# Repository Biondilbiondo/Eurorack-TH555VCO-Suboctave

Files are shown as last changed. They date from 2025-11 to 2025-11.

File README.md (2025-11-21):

# TH555 SUB VCO

This is a remake of eurorack module for the excellent and fully-analog Thomas Henry 555 VCO [[1](https://electro-music.com/forum/topic-54623.html)] [[2](https://github.com/gerb-ster/TH-555-VCO)] [[3](https://www.eddybergman.com/2020/12/synthesizer-build-part-37-thomas-henry.html)].
I added some features and tweaks to the module (inventing very little...) to make it more appealing to be built in 2025.

1. Added a sub-octave stage chained with the module to generate a square, sawtooth and triangle waves 1 octave below, and a square wave 2 octaves below; this is basically taken from [[4](https://electro-music.com/wiki/pmwiki.php?n=Schematics.WaveThingMultiply-DivideWaveShapingCircuit)] 
2. Added an octave switch using a rotatory switch widely available in the DIY eurorack stores (the same of MTM turing machine [[5](https://www.musicthing.co.uk/Turing-Machine/)]
3. Drastically reduced the range of coarse/fine knobs to be used in combination with the octave switch (COARSE = +/- 2 octaves; FINE = +/- 3 semitones)
4. Added a LFO function, with larger range for the COARSE/FINE knobs, and a configurable basic frequence.
5. Switched input/output to thonkiconn
6. Removed the manually matched pair of transistors in favor of the in-chip matched BCM857BS
7. All components are now SMT (easy hand soldered SOIC, 0603 passives)

## Versions
# 0.1
First take, this version had several errors, both schematic copying errors and in the sub-octabve section. This version was used to develop v 0.2 but sources are lost.

# 0.2
Almost completely working version. 

Improvements wrt vs 0.1
- ✅ The clock feed circuit for the sub-octave is completely redesigned
- ✅ Several minor copying errors have been corrected
- ✅ The panel for octave switch has been corrected
- ✅ Resistors for the octave switch are now marked in the correct order
- ✅ All the trimmer are now in the same format (3214X) + name added for each
Problems:
- ❌ Transistors footprint is incorrect (they shuld be mounted upside-down)
- ❌ The frontpanel interface is not optimal
- ❌ Octave switch is not properly tuned depending on the fluctuation of resistors
- ❌ Calibration is not easy

Also this version was lost.
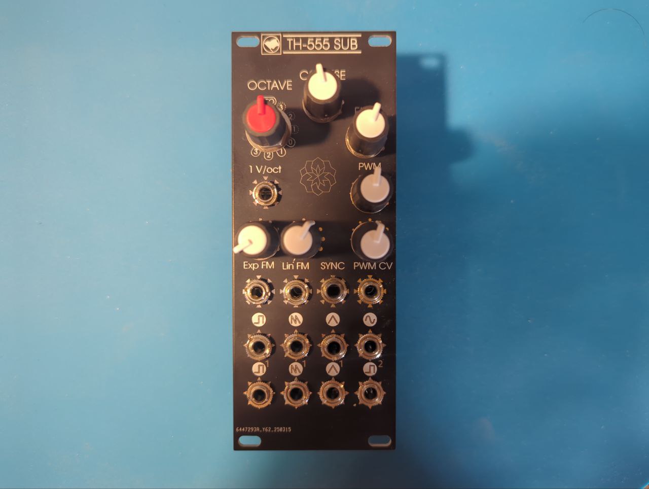
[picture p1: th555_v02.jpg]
Assembled module


# 0.3
This version is the current one, waiting to be built, it was designed starting from reverse-eng of v0.2 from production files. 

Improvements wrt vs 0.2
- ✅ Front panel redesign 
- ✅ Added leds to visualize the wave
- ✅ Corrected footprint of transistors
- ✅ Added a trimmer for octave-switch calibration

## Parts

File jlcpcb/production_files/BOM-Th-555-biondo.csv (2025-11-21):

Comment | Designator | Footprint | LCSC | Quantity
100n | C20 | C_0603_1608Metric_Pad1.08x0.95mm_HandSolder |  | 1
100n | C8 | C_0603_1608Metric_Pad1.08x0.95mm_HandSolder |  | 1
100k | R71 | R_0603_1608Metric_Pad0.98x0.95mm_HandSolder |  | 1
100k | R93 | R_0603_1608Metric_Pad0.98x0.95mm_HandSolder |  | 1
Conn_01x04 | J18 | PinHeader_1x04_P2.54mm_Vertical |  | 1
100k | R76 | R_0603_1608Metric_Pad0.98x0.95mm_HandSolder |  | 1
7.15k | R6 | R_0603_1608Metric_Pad0.98x0.95mm_HandSolder |  | 1
100k | RV11 | Potentiometer_Bourns_3214X_Vertical |  | 1
10k | R75 | R_0603_1608Metric_Pad0.98x0.95mm_HandSolder |  | 1
100k | R25 | R_0603_1608Metric_Pad0.98x0.95mm_HandSolder |  | 1
100R | RV13 | Potentiometer_Bourns_3214X_Vertical |  | 1
11.8k | R38 | R_0603_1608Metric_Pad0.98x0.95mm_HandSolder |  | 1
7.15k | R5 | R_0603_1608Metric_Pad0.98x0.95mm_HandSolder |  | 1
10k | R90 | R_0603_1608Metric_Pad0.98x0.95mm_HandSolder |  | 1
100k | R69 | R_0603_1608Metric_Pad0.98x0.95mm_HandSolder |  | 1
1.5M | R56 | R_0603_1608Metric_Pad0.98x0.95mm_HandSolder |  | 1
10u | C22 | CP_Elec_4x5.8 |  | 1
1n | C24 | C_0603_1608Metric |  | 1
100k | R79 | R_0603_1608Metric_Pad0.98x0.95mm_HandSolder |  | 1
1k | R96 | R_0603_1608Metric_Pad0.98x0.95mm_HandSolder |  | 1
2.2k | R80 | R_0603_1608Metric_Pad0.98x0.95mm_HandSolder |  | 1
150k | R51 | R_0603_1608Metric_Pad0.98x0.95mm_HandSolder |  | 1
10k | R55 | R_0603_1608Metric_Pad0.98x0.95mm_HandSolder |  | 1
100k | R70 | R_0603_1608Metric_Pad0.98x0.95mm_HandSolder |  | 1
100n | C15 | C_0603_1608Metric_Pad1.08x0.95mm_HandSolder |  | 1
1.5k | R12 | R_0603_1608Metric_Pad0.98x0.95mm_HandSolder |  | 1
100k | R98 | R_0603_1608Metric_Pad0.98x0.95mm_HandSolder |  | 1
1M | R48 | R_0603_1608Metric_Pad0.98x0.95mm_HandSolder |  | 1
100k | R88 | R_0603_1608Metric_Pad0.98x0.95mm_HandSolder |  | 1
TL072 | U3 | SOIC-8_3.9x4.9mm_P1.27mm |  | 1
4.7k | R22 | R_0603_1608Metric_Pad0.98x0.95mm_HandSolder |  | 1
2k +3500ppm/K | R53 | R_0603_1608Metric_Pad0.98x0.95mm_HandSolder |  | 1
200k | R30 | R_0603_1608Metric_Pad0.98x0.95mm_HandSolder |  | 1
220n | C14 | C_0603_1608Metric_Pad1.08x0.95mm_HandSolder |  | 1
100n | C17 | C_0603_1608Metric_Pad1.08x0.95mm_HandSolder |  | 1
390R | R10 | R_0603_1608Metric_Pad0.98x0.95mm_HandSolder |  | 1
5.6k | R13 | R_0603_1608Metric_Pad0.98x0.95mm_HandSolder |  | 1
Conn_02x05_Odd_Even | J20 | IDC-Header_2x05_P2.54mm_Vertical |  | 1
1M | R19 | R_0603_1608Metric_Pad0.98x0.95mm_HandSolder |  | 1
100n | C9 | C_0603_1608Metric_Pad1.08x0.95mm_HandSolder |  | 1
1k | R61 | R_0603_1608Metric_Pad0.98x0.95mm_HandSolder |  | 1
100k | R83 | R_0603_1608Metric_Pad0.98x0.95mm_HandSolder |  | 1
237k | R29 | R_0603_1608Metric_Pad0.98x0.95mm_HandSolder |  | 1
20k | R54 | R_0603_1608Metric_Pad0.98x0.95mm_HandSolder |  | 1
100k | R59 | R_0603_1608Metric_Pad0.98x0.95mm_HandSolder |  | 1
10k | R89 | R_0603_1608Metric_Pad0.98x0.95mm_HandSolder |  | 1
10k | R49 | R_0603_1608Metric_Pad0.98x0.95mm_HandSolder |  | 1
TL074 | U7 | SOIC-14_3.9x8.7mm_P1.27mm |  | 1
TL072 | U9 | SOIC-8_3.9x4.9mm_P1.27mm |  | 1
25k | R2 | R_0603_1608Metric_Pad0.98x0.95mm_HandSolder |  | 1
47k | R94 | R_0603_1608Metric_Pad0.98x0.95mm_HandSolder |  | 1
2.2k | R52 | R_0603_1608Metric_Pad0.98x0.95mm_HandSolder |  | 1
10k | R91 | R_0603_1608Metric_Pad0.98x0.95mm_HandSolder |  | 1
100k | R73 | R_0603_1608Metric_Pad0.98x0.95mm_HandSolder |  | 1
1k | R95 | R_0603_1608Metric_Pad0.98x0.95mm_HandSolder |  | 1
10.0k | R4 | R_0603_1608Metric_Pad0.98x0.95mm_HandSolder |  | 1
1k | R65 | R_0603_1608Metric_Pad0.98x0.95mm_HandSolder |  | 1
100n | C7 | C_0603_1608Metric_Pad1.08x0.95mm_HandSolder |  | 1
1n | C5 | C_0603_1608Metric_Pad1.08x0.95mm_HandSolder |  | 1
100k | R97 | R_0603_1608Metric_Pad0.98x0.95mm_HandSolder |  | 1
100k | R34 | R_0603_1608Metric_Pad0.98x0.95mm_HandSolder |  | 1
100p | C13 | C_0603_1608Metric_Pad1.08x0.95mm_HandSolder |  | 1
100n | C10 | C_0603_1608Metric_Pad1.08x0.95mm_HandSolder |  | 1
100n | C18 | C_0603_1608Metric_Pad1.08x0.95mm_HandSolder |  | 1
100k | R15 | R_0603_1608Metric_Pad0.98x0.95mm_HandSolder |  | 1
1M | R50 | R_0603_1608Metric_Pad0.98x0.95mm_HandSolder |  | 1
100k | R74 | R_0603_1608Metric_Pad0.98x0.95mm_HandSolder |  | 1
100k | R24 | R_0603_1608Metric_Pad0.98x0.95mm_HandSolder |  | 1
TL074 | U5 | SOIC-14_3.9x8.7mm_P1.27mm |  | 1
MMBT3904 | Q1 | SOT-23 |  | 1
4.7k | R26 | R_0603_1608Metric_Pad0.98x0.95mm_HandSolder |  | 1
10k | R35 | R_0603_1608Metric_Pad0.98x0.95mm_HandSolder |  | 1
100n | C1 | C_0603_1608Metric_Pad1.08x0.95mm_HandSolder |  | 1
1k | R63 | R_0603_1608Metric_Pad0.98x0.95mm_HandSolder |  | 1
237k | R28 | R_0603_1608Metric_Pad0.98x0.95mm_HandSolder |  | 1
100k | R27 | R_0603_1608Metric_Pad0.98x0.95mm_HandSolder |  | 1
100k | R17 | R_0603_1608Metric_Pad0.98x0.95mm_HandSolder |  | 1
22k | R58 | R_0603_1608Metric_Pad0.98x0.95mm_HandSolder |  | 1
10k | R77 | R_0603_1608Metric_Pad0.98x0.95mm_HandSolder |  | 1
MMBT3906 | Q7 | SOT-23 |  | 1
10k | R43 | R_0603_1608Metric_Pad0.98x0.95mm_HandSolder |  | 1
100k | R60 | R_0603_1608Metric_Pad0.98x0.95mm_HandSolder |  | 1
100k | RV8 | Potentiometer_Bourns_3214X_Vertical |  | 1
14.0k | R36 | R_0603_1608Metric_Pad0.98x0.95mm_HandSolder |  | 1
470p | C6 | C_0603_1608Metric_Pad1.08x0.95mm_HandSolder |  | 1
10n | C25 | C_0603_1608Metric |  | 1
2200pF C0G/NP0 | C2 | C_0603_1608Metric_Pad1.08x0.95mm_HandSolder |  | 1
10k | R9 | R_0603_1608Metric_Pad0.98x0.95mm_HandSolder |  | 1
1.5k | R8 | R_0603_1608Metric_Pad0.98x0.95mm_HandSolder |  | 1
100k | R18 | R_0603_1608Metric_Pad0.98x0.95mm_HandSolder |  | 1
10k | R82 | R_0603_1608Metric_Pad0.98x0.95mm_HandSolder |  | 1
MMBT3904 | Q6 | SOT-23 |  | 1
100n | C11 | C_0603_1608Metric_Pad1.08x0.95mm_HandSolder |  | 1
10u | C19 | CP_Elec_4x5.8 |  | 1
100k | R20 | R_0603_1608Metric_Pad0.98x0.95mm_HandSolder |  | 1
LM13700 | U1 | SOIC-16_3.9x9.9mm_P1.27mm |  | 1
100n | C21 | C_0603_1608Metric_Pad1.08x0.95mm_HandSolder |  | 1
1N4148W | D2 | D_SOD-123 |  | 1
1M | R16 | R_0603_1608Metric_Pad0.98x0.95mm_HandSolder |  | 1
6.04k | R7 | R_0603_1608Metric_Pad0.98x0.95mm_HandSolder |  | 1
10k | R31 | R_0603_1608Metric_Pad0.98x0.95mm_HandSolder |  | 1
25k | RV9 | Potentiometer_Bourns_3214X_Vertical |  | 1
2.2M | R86 | R_0603_1608Metric_Pad0.98x0.95mm_HandSolder |  | 1
100n | C4 | C_0603_1608Metric_Pad1.08x0.95mm_HandSolder |  | 1
100n | C3 | C_0603_1608Metric_Pad1.08x0.95mm_HandSolder |  | 1
22k | R14 | R_0603_1608Metric_Pad0.98x0.95mm_HandSolder |  | 1
4013 | U8 | SOIC-14_3.9x8.7mm_P1.27mm |  | 1
MMBT3904 | Q5 | SOT-23-3_npn |  | 1
100k | R21 | R_0603_1608Metric_Pad0.98x0.95mm_HandSolder |  | 1
8.45k | R3 | R_0603_1608Metric_Pad0.98x0.95mm_HandSolder |  | 1
330k | R47 | R_0603_1608Metric_Pad0.98x0.95mm_HandSolder |  | 1
ICM7555xB | U2 | SOIC-8_3.9x4.9mm_P1.27mm |  | 1
1k | R62 | R_0603_1608Metric_Pad0.98x0.95mm_HandSolder |  | 1
10k | R87 | R_0603_1608Metric_Pad0.98x0.95mm_HandSolder |  | 1
100k | RV14 | Potentiometer_Bourns_3214X_Vertical |  | 1
300k | R11 | R_0603_1608Metric_Pad0.98x0.95mm_HandSolder |  | 1
2.2k | R85 | R_0603_1608Metric_Pad0.98x0.95mm_HandSolder |  | 1
1k | R68 | R_0603_1608Metric_Pad0.98x0.95mm_HandSolder |  | 1
51k | R84 | R_0603_1608Metric_Pad0.98x0.95mm_HandSolder |  | 1
1k | R64 | R_0603_1608Metric_Pad0.98x0.95mm_HandSolder |  | 1
10k | R46 | R_0603_1608Metric_Pad0.98x0.95mm_HandSolder |  | 1
BCM857BS | U6 | SOT-363_SC-70-6 |  | 1
2.2M | R45 | R_0603_1608Metric_Pad0.98x0.95mm_HandSolder |  | 1
200k | R32 | R_0603_1608Metric_Pad0.98x0.95mm_HandSolder |  | 1
TL074 | U4 | SOIC-14_3.9x8.7mm_P1.27mm |  | 1
1k | R67 | R_0603_1608Metric_Pad0.98x0.95mm_HandSolder |  | 1
1N4148W | D1 | D_SOD-123 |  | 1
1k | R66 | R_0603_1608Metric_Pad0.98x0.95mm_HandSolder |  | 1
100k | RV12 | Potentiometer_Bourns_3214X_Vertical |  | 1
100n | C12 | C_0603_1608Metric_Pad1.08x0.95mm_HandSolder |  | 1
10k | R92 | R_0603_1608Metric_Pad0.98x0.95mm_HandSolder |  | 1
MMBF4391 | Q3 | SOT-23 |  | 1
3k | R81 | R_0603_1608Metric_Pad0.98x0.95mm_HandSolder |  | 1
390R | R23 | R_0603_1608Metric_Pad0.98x0.95mm_HandSolder |  | 1
Conn_01x12 | J17 | PinHeader_1x12_P2.54mm_Vertical |  | 1
2.2k | R78 | R_0603_1608Metric_Pad0.98x0.95mm_HandSolder |  | 1
100k | R44 | R_0603_1608Metric_Pad0.98x0.95mm_HandSolder |  | 1
MMBF4391 | Q2 | SOT-23 |  | 1
16.5k | R37 | R_0603_1608Metric_Pad0.98x0.95mm_HandSolder |  | 1
100k | R42 | R_0603_1608Metric_Pad0.98x0.95mm_HandSolder |  | 1
Conn_01x04 | J19 | PinHeader_1x04_P2.54mm_Vertical |  | 1
10k | RV10 | Potentiometer_Bourns_3214X_Vertical |  | 1
2k | R72 | R_0603_1608Metric_Pad0.98x0.95mm_HandSolder |  | 1
20k | R57 | R_0603_1608Metric_Pad0.98x0.95mm_HandSolder |  | 1
39k | R41 | R_0603_1608Metric_Pad0.98x0.95mm_HandSolder |  | 1
MMBT3904 | Q4 | SOT-23-3_npn |  | 1
120k | R40 | R_0603_1608Metric_Pad0.98x0.95mm_HandSolder |  | 1
100n | C16 | C_0603_1608Metric_Pad1.08x0.95mm_HandSolder |  | 1
25k | R1 | R_0603_1608Metric_Pad0.98x0.95mm_HandSolder |  | 1
100k | R33 | R_0603_1608Metric_Pad0.98x0.95mm_HandSolder |  | 1
100n | C23 | C_0603_1608Metric_Pad1.08x0.95mm_HandSolder |  | 1
ICM7555xB | U10 | SOIC-8_3.9x4.9mm_P1.27mm |  | 1
137k | R39 | R_0603_1608Metric_Pad0.98x0.95mm_HandSolder |  | 1
1n | C26 | C_0603_1608Metric_Pad1.08x0.95mm_HandSolder |  | 1

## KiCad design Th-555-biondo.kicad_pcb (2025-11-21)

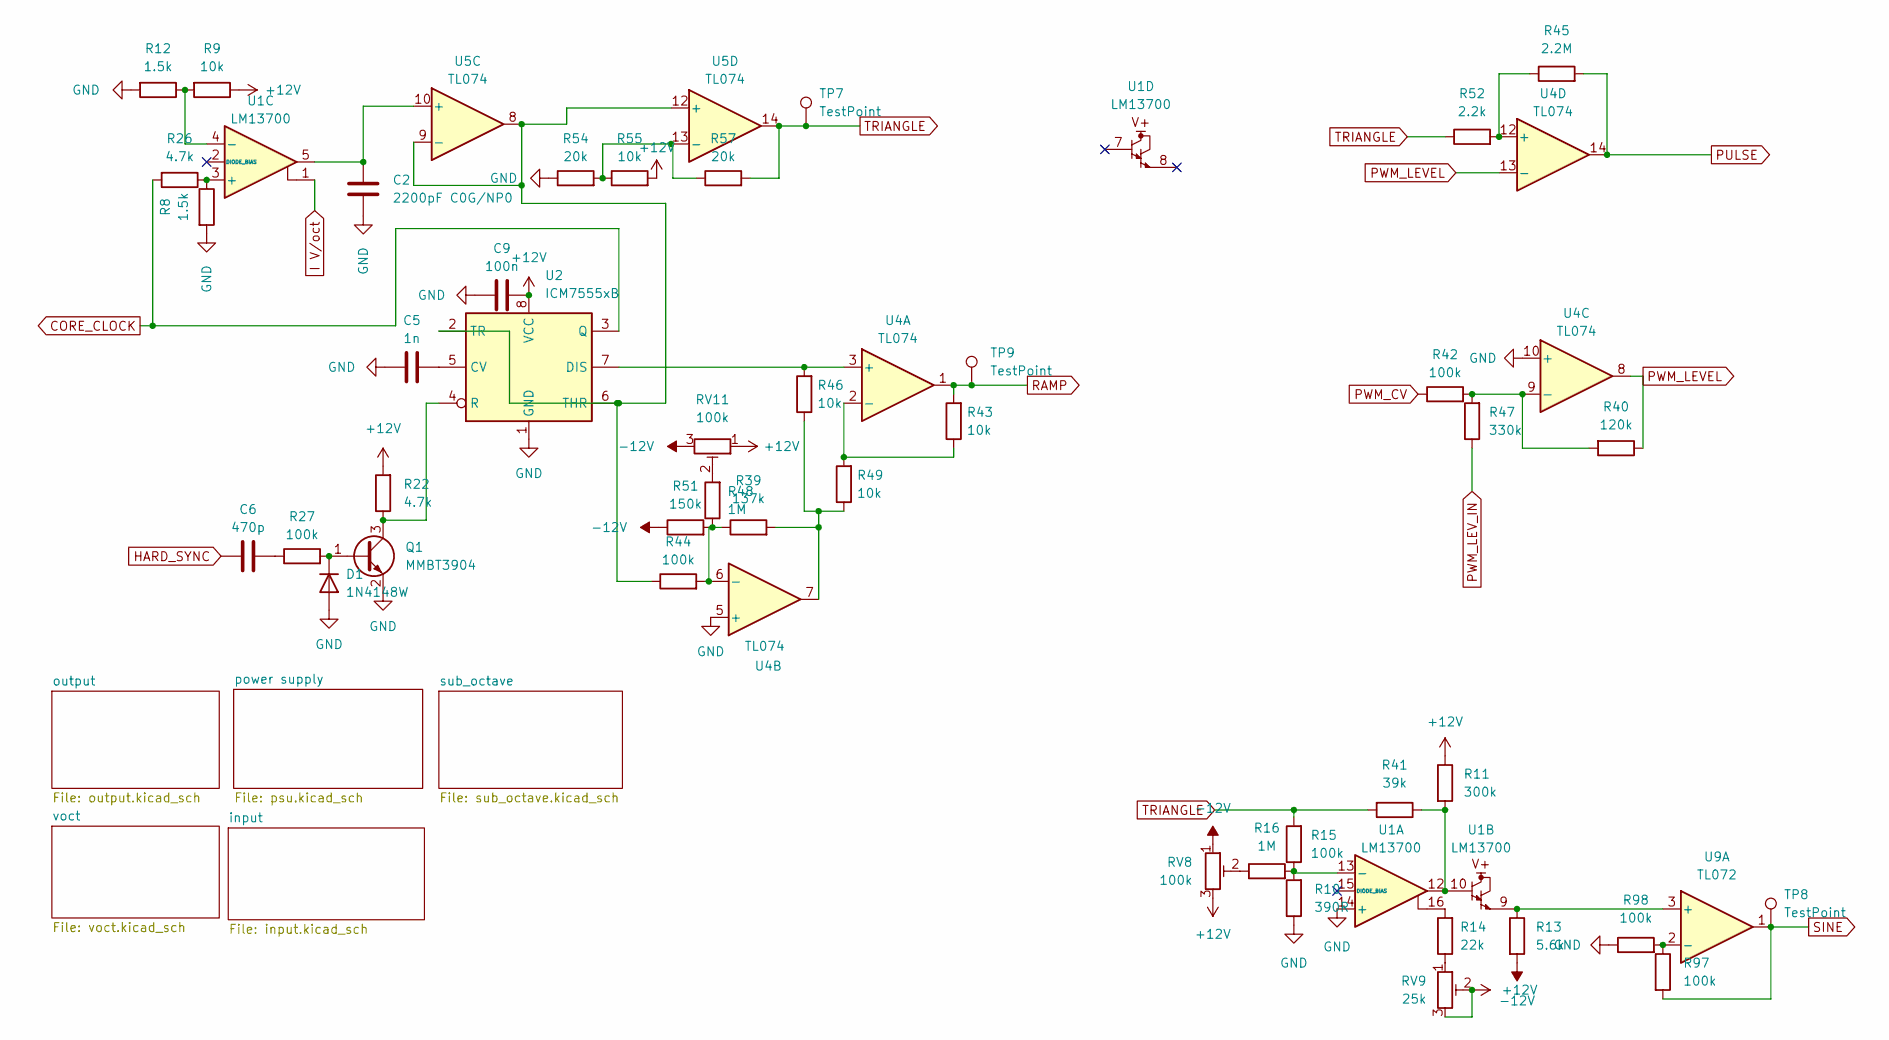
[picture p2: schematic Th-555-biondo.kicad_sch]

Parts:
C2: 2200pF C0G/NP0; C_0603_1608Metric_Pad1.08x0.95mm_HandSolder
C5: 1n; C_0603_1608Metric_Pad1.08x0.95mm_HandSolder
C6: 470p; C_0603_1608Metric_Pad1.08x0.95mm_HandSolder
C9: 100n; C_0603_1608Metric_Pad1.08x0.95mm_HandSolder
D1: 1N4148W; D_SOD-123
Q1: MMBT3904; SOT-23
R8, R12: 1.5k; R_0603_1608Metric_Pad0.98x0.95mm_HandSolder
R9, R43, R46, R49, R55: 10k; R_0603_1608Metric_Pad0.98x0.95mm_HandSolder
R10: 390R; R_0603_1608Metric_Pad0.98x0.95mm_HandSolder
R11: 300k; R_0603_1608Metric_Pad0.98x0.95mm_HandSolder
R13: 5.6k; R_0603_1608Metric_Pad0.98x0.95mm_HandSolder
R14: 22k; R_0603_1608Metric_Pad0.98x0.95mm_HandSolder
R15, R27, R42, R44, R97, R98: 100k; R_0603_1608Metric_Pad0.98x0.95mm_HandSolder
R16, R48: 1M; R_0603_1608Metric_Pad0.98x0.95mm_HandSolder
R22, R26: 4.7k; R_0603_1608Metric_Pad0.98x0.95mm_HandSolder
R39: 137k; R_0603_1608Metric_Pad0.98x0.95mm_HandSolder
R40: 120k; R_0603_1608Metric_Pad0.98x0.95mm_HandSolder
R41: 39k; R_0603_1608Metric_Pad0.98x0.95mm_HandSolder
R45: 2.2M; R_0603_1608Metric_Pad0.98x0.95mm_HandSolder
R47: 330k; R_0603_1608Metric_Pad0.98x0.95mm_HandSolder
R51: 150k; R_0603_1608Metric_Pad0.98x0.95mm_HandSolder
R52: 2.2k; R_0603_1608Metric_Pad0.98x0.95mm_HandSolder
R54, R57: 20k; R_0603_1608Metric_Pad0.98x0.95mm_HandSolder
RV8, RV11: 100k; Potentiometer_Bourns_3214X_Vertical
RV9: 25k; Potentiometer_Bourns_3214X_Vertical
TP7, TP8, TP9: TestPoint; TestPoint_Pad_D1.0mm
U1: LM13700; SOIC-16_3.9x9.9mm_P1.27mm
U2: ICM7555xB; SOIC-8_3.9x4.9mm_P1.27mm
U4, U5: TL074; SOIC-14_3.9x8.7mm_P1.27mm
U9: TL072; SOIC-8_3.9x4.9mm_P1.27mm

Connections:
+12V: C9.2, R9.1, R11.1, R22.2, R55.2, RV8.3, RV9.2, RV9.3, RV11.1, U2.8 (VCC); also elsewhere on the board
-12V: R13.2, R51.1, RV8.1, RV11.3; also elsewhere on the board
CORE_CLOCK: R26.2, U2.3 (Q); also elsewhere on the board
HARD_SYNC: C6.1; also elsewhere on the board
I V/oct: U1.1; also elsewhere on the board
unnamed: C6.2, R27.1
unnamed: D1.1 (K), Q1.1 (B), R27.2
unnamed: Q1.3 (C), R22.1, U2.4 (R)
unnamed: R11.2, R41.1, U1.10, U1.12
unnamed: R14.1, RV9.1
unnamed: R14.2, U1.16
unnamed: R16.1, RV8.2
unnamed: R39.2, R46.1, R49.1, U4.7
unnamed: R48.2, RV11.2
unnamed: R10.2, R15.1, R16.2, U1.13 (-)
unnamed: R8.1, R26.1, U1.3 (+)
unnamed: R9.2, R12.1, U1.4 (-)
unnamed: C5.2, U2.5 (CV)
unnamed: R46.2, U2.7 (DIS), U4.3 (+)
unnamed: R44.1, U2.2 (TR), U2.6 (THR), U5.8, U5.9 (-), U5.12 (+)
unnamed: R43.1, R49.2, U4.2 (-)
unnamed: R39.1, R44.2, R48.1, R51.2, U4.6 (-)
unnamed: R40.2, R42.2, R47.2, U4.9 (-)
unnamed: R45.1, R52.2, U4.12 (+)
unnamed: C2.1, U1.5, U5.10 (+)
unnamed: R54.2, R55.1, R57.1, U5.13 (-)
unnamed: R13.1, U1.9, U9.3 (+)
unnamed: R97.1, R98.2, U9.2 (-)
PULSE: R45.2, U4.14; also elsewhere on the board
PWM_CV: R42.1; also elsewhere on the board
PWM_LEVEL: R40.1, U4.8, U4.13 (-); also elsewhere on the board
PWM_LEV_IN: R47.1; also elsewhere on the board
RAMP: R43.2, TP9.1, U4.1; also elsewhere on the board
SINE: R97.2, TP8.1, U9.1; also elsewhere on the board
TRIANGLE: R15.2, R41.2, R52.1, R57.2, TP7.1, U5.14; also elsewhere on the board

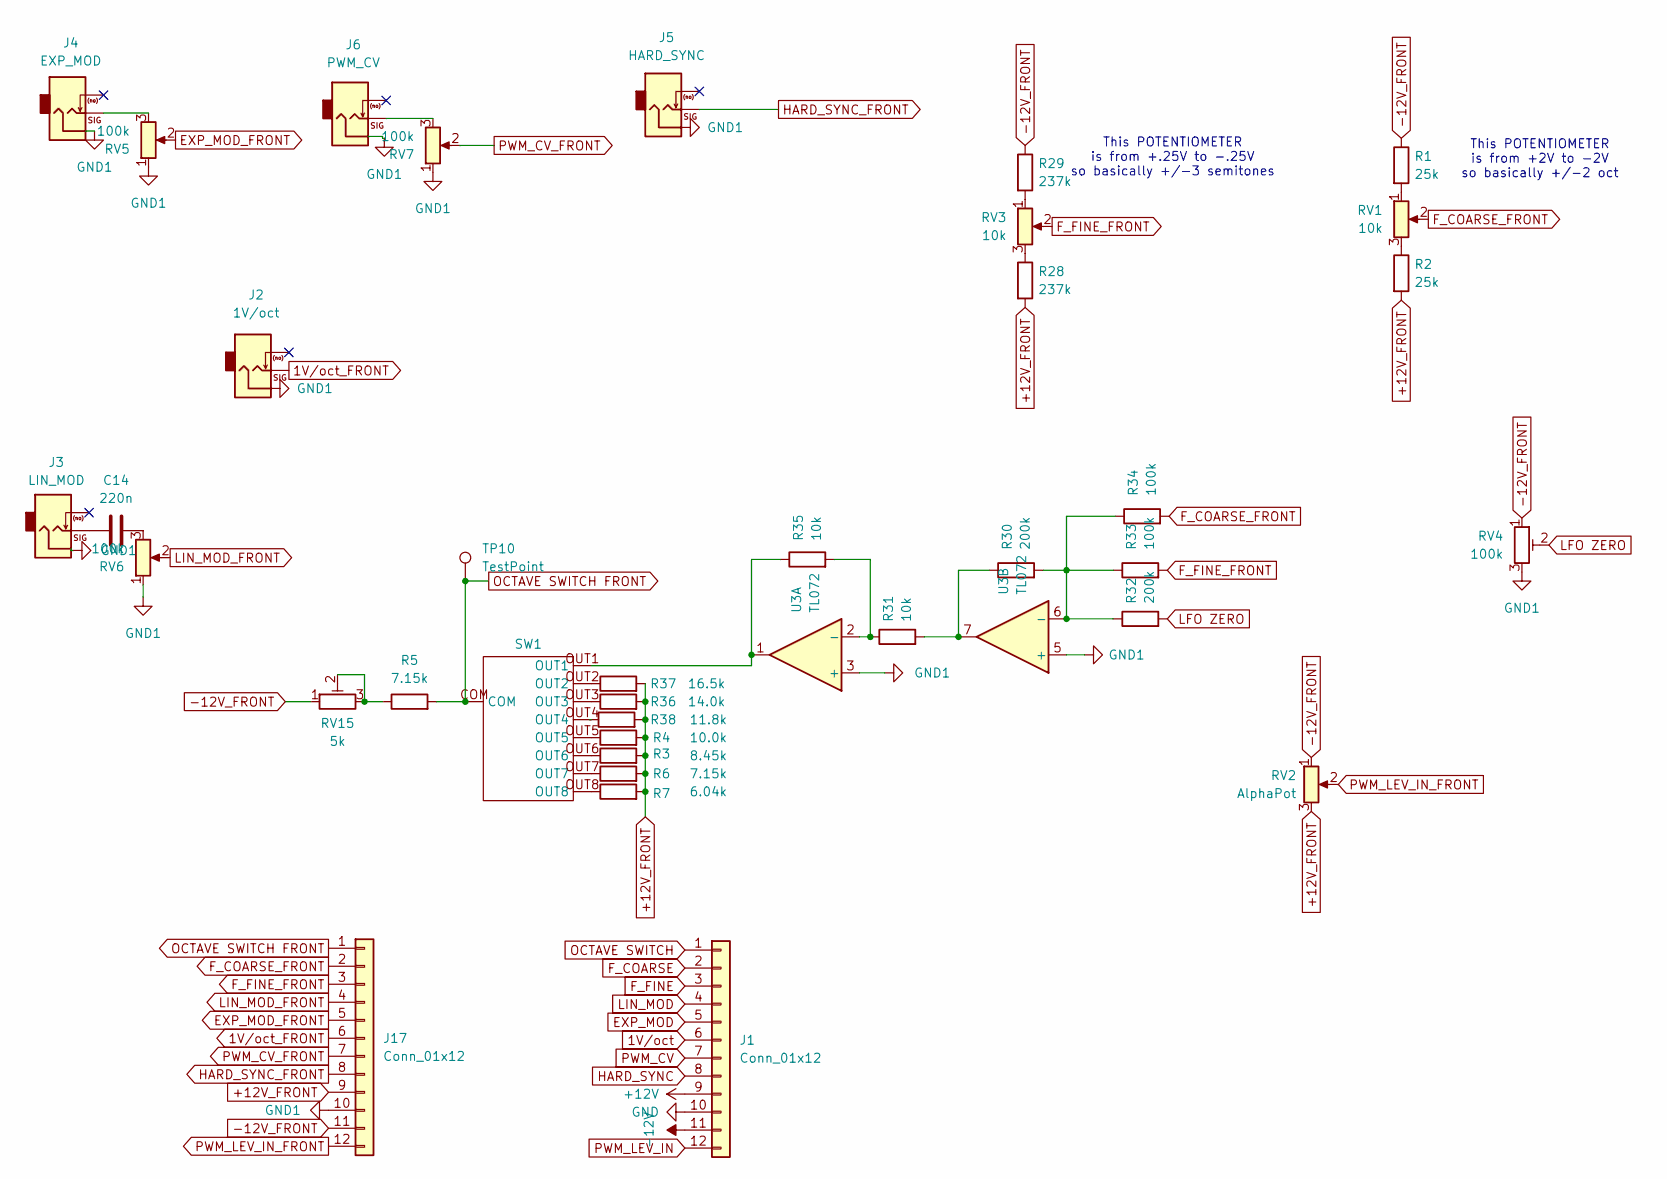
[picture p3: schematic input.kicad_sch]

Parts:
C14: 220n; C_0603_1608Metric_Pad1.08x0.95mm_HandSolder
J1: Conn_01x12; PinSocket_1x12_P2.54mm_Vertical
J2: 1V/oct; Jack_3.5mm_QingPu_WQP-PJ398SM_Vertical_CircularHoles
J3: LIN_MOD; Jack_3.5mm_QingPu_WQP-PJ398SM_Vertical_CircularHoles
J4: EXP_MOD; Jack_3.5mm_QingPu_WQP-PJ398SM_Vertical_CircularHoles
J5: HARD_SYNC; Jack_3.5mm_QingPu_WQP-PJ398SM_Vertical_CircularHoles
J6: PWM_CV; Jack_3.5mm_QingPu_WQP-PJ398SM_Vertical_CircularHoles
J17: Conn_01x12; PinHeader_1x12_P2.54mm_Vertical
R1, R2: 25k; R_0603_1608Metric_Pad0.98x0.95mm_HandSolder
R3: 8.45k; R_0603_1608Metric_Pad0.98x0.95mm_HandSolder
R4: 10.0k; R_0603_1608Metric_Pad0.98x0.95mm_HandSolder
R5, R6: 7.15k; R_0603_1608Metric_Pad0.98x0.95mm_HandSolder
R7: 6.04k; R_0603_1608Metric_Pad0.98x0.95mm_HandSolder
R28, R29: 237k; R_0603_1608Metric_Pad0.98x0.95mm_HandSolder
R30, R32: 200k; R_0603_1608Metric_Pad0.98x0.95mm_HandSolder
R31, R35: 10k; R_0603_1608Metric_Pad0.98x0.95mm_HandSolder
R33, R34: 100k; R_0603_1608Metric_Pad0.98x0.95mm_HandSolder
R36: 14.0k; R_0603_1608Metric_Pad0.98x0.95mm_HandSolder
R37: 16.5k; R_0603_1608Metric_Pad0.98x0.95mm_HandSolder
R38: 11.8k; R_0603_1608Metric_Pad0.98x0.95mm_HandSolder
RV1, RV3: 10k; Potentiometer_Alpha_RD901F-40-00D_Single_Vertical
RV2: AlphaPot; Potentiometer_Alpha_RD901F-40-00D_Single_Vertical
RV4: 100k; Potentiometer_Bourns_3214X_Vertical
RV5, RV6, RV7: 100k; Potentiometer_Alpha_RD901F-40-00D_Single_Vertical
RV15: 5k; Potentiometer_Bourns_3214X_Vertical
SW1: TH_rot_switch
TP10: TestPoint; TestPoint_Pad_D1.0mm
U3: TL072; SOIC-8_3.9x4.9mm_P1.27mm

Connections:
1V/oct: J1.6; also elsewhere on the board
1V/oct_FRONT: J2.T, J17.6
+12V: J1.9; also elsewhere on the board
+12V_FRONT: J17.9, R2.2, R3.2, R4.2, R6.2, R7.2, R28.2, R36.2, R37.2, R38.2, RV2.3; also elsewhere on the board
-12V: J1.11; also elsewhere on the board
-12V_FRONT: J17.11, R1.1, R29.1, RV2.1, RV4.1, RV15.1; also elsewhere on the board
EXP_MOD: J1.5; also elsewhere on the board
EXP_MOD_FRONT: J17.5, RV5.2
F_COARSE: J1.2; also elsewhere on the board
F_COARSE_FRONT: J17.2, R34.2, RV1.2
F_FINE: J1.3; also elsewhere on the board
F_FINE_FRONT: J17.3, R33.2, RV3.2
HARD_SYNC: J1.8; also elsewhere on the board
HARD_SYNC_FRONT: J5.T, J17.8
LFO ZERO: R32.2, RV4.2
LIN_MOD: J1.4; also elsewhere on the board
LIN_MOD_FRONT: J17.4, RV6.2
unnamed: C14.1, J3.T
unnamed: C14.2, RV6.3
unnamed: J4.T, RV5.3
unnamed: J6.T, RV7.3
unnamed: R1.2, RV1.1
unnamed: R2.1, RV1.3
unnamed: R3.1, SW1.OUT6
unnamed: R4.1, SW1.OUT5
unnamed: R5.1, RV15.2, RV15.3
unnamed: R6.1, SW1.OUT7
unnamed: R7.1, SW1.OUT8
unnamed: R28.1, RV3.3
unnamed: R29.2, RV3.1
unnamed: R30.1, R31.2, U3.7
unnamed: R35.1, SW1.OUT1, U3.1
unnamed: R36.1, SW1.OUT3
unnamed: R37.1, SW1.OUT2
unnamed: R38.1, SW1.OUT4
unnamed: R31.1, R35.2, U3.2 (-)
unnamed: R30.2, R32.1, R33.1, R34.1, U3.6 (-)
OCTAVE SWITCH: J1.1; also elsewhere on the board
OCTAVE SWITCH FRONT: J17.1, R5.2, SW1.COM, TP10.1
PWM_CV: J1.7; also elsewhere on the board
PWM_CV_FRONT: J17.7, RV7.2
PWM_LEV_IN: J1.12; also elsewhere on the board
PWM_LEV_IN_FRONT: J17.12, RV2.2

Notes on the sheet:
This POTENTIOMETER is from +.25V to -.25V so basically +/-3 semitones
This POTENTIOMETER is from +2V to -2V so basically +/-2 oct

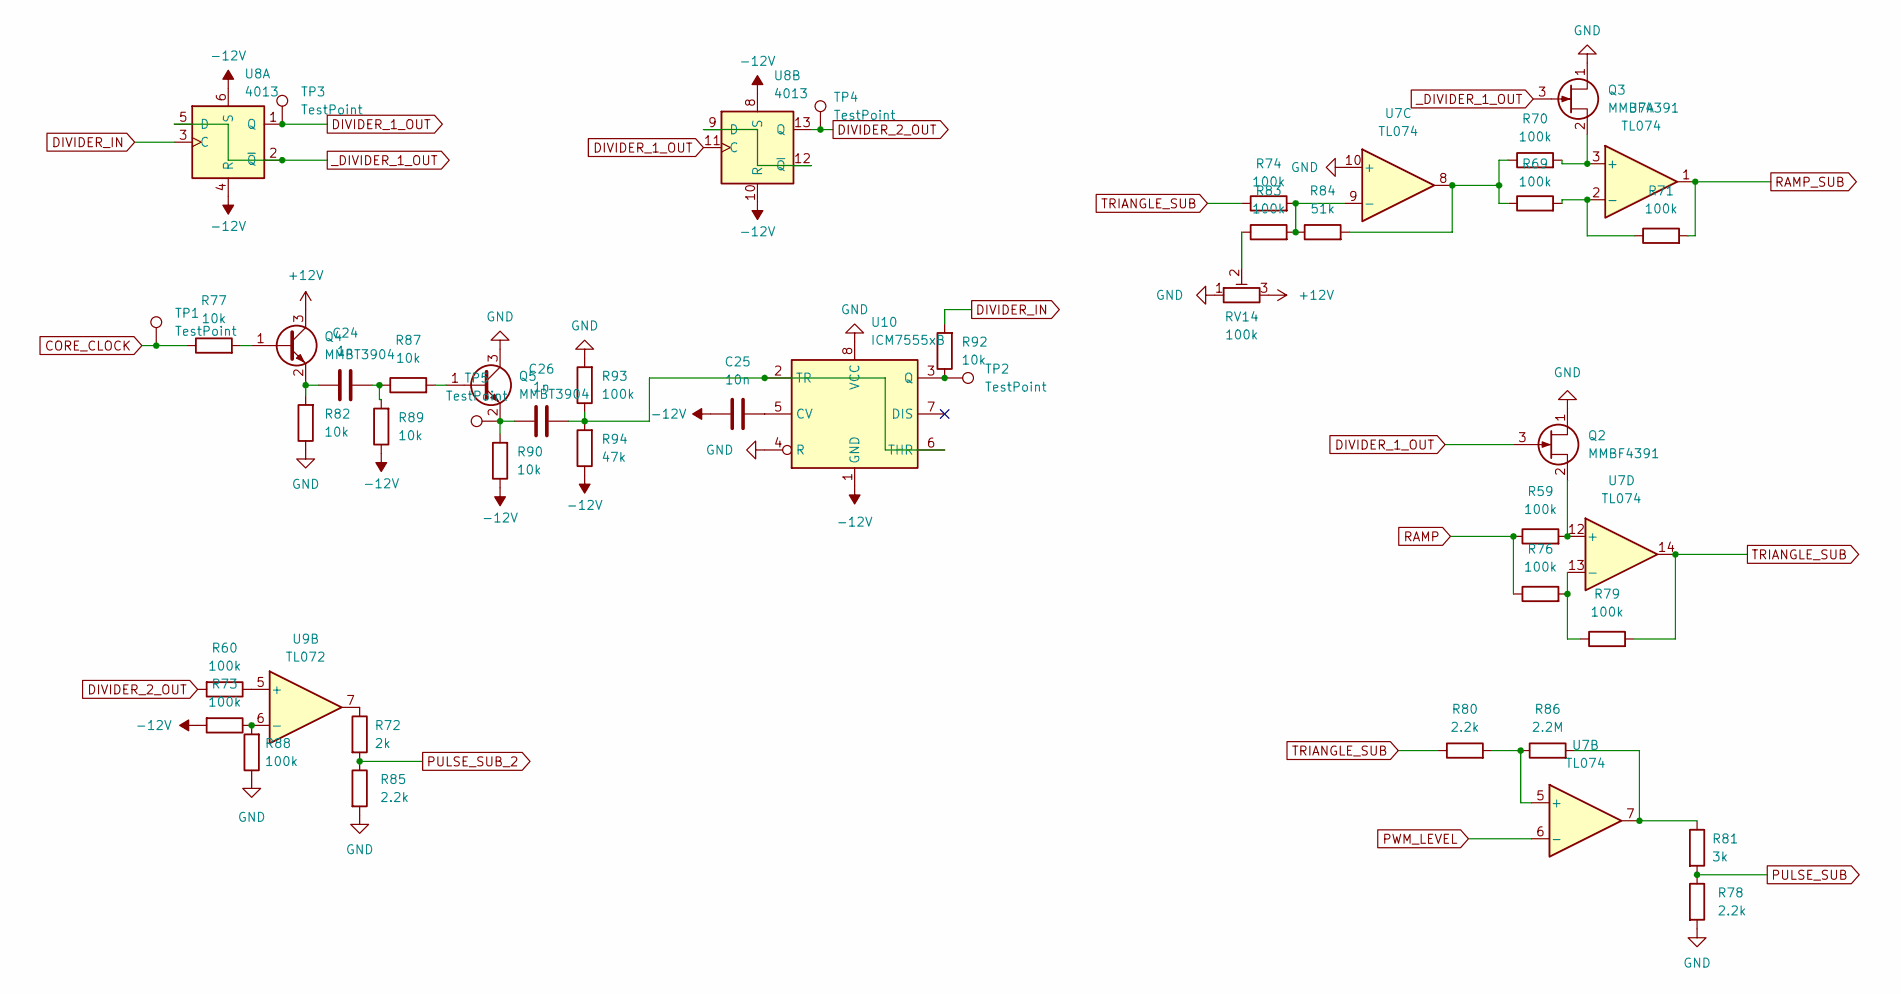
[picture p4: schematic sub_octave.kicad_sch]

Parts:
C24: 1n; C_0603_1608Metric
C25: 10n; C_0603_1608Metric
C26: 1n; C_0603_1608Metric_Pad1.08x0.95mm_HandSolder
Q2, Q3: MMBF4391; SOT-23
Q4, Q5: MMBT3904; SOT-23-3_npn
R59, R60, R69, R70, R71, R73, R74, R76, R79, R83, R88, R93: 100k; R_0603_1608Metric_Pad0.98x0.95mm_HandSolder
R72: 2k; R_0603_1608Metric_Pad0.98x0.95mm_HandSolder
R77, R82, R87, R89, R90, R92: 10k; R_0603_1608Metric_Pad0.98x0.95mm_HandSolder
R78, R80, R85: 2.2k; R_0603_1608Metric_Pad0.98x0.95mm_HandSolder
R81: 3k; R_0603_1608Metric_Pad0.98x0.95mm_HandSolder
R84: 51k; R_0603_1608Metric_Pad0.98x0.95mm_HandSolder
R86: 2.2M; R_0603_1608Metric_Pad0.98x0.95mm_HandSolder
R94: 47k; R_0603_1608Metric_Pad0.98x0.95mm_HandSolder
RV14: 100k; Potentiometer_Bourns_3214X_Vertical
TP1, TP2, TP3, TP4, TP5: TestPoint; TestPoint_Pad_D1.0mm
U7: TL074; SOIC-14_3.9x8.7mm_P1.27mm
U8: 4013; SOIC-14_3.9x8.7mm_P1.27mm
U9: TL072; SOIC-8_3.9x4.9mm_P1.27mm
U10: ICM7555xB; SOIC-8_3.9x4.9mm_P1.27mm

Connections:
+12V: Q4.3 (C), RV14.3; also elsewhere on the board
-12V: C25.1, R73.2, R89.1, R90.1, R94.1, U8.4 (R), U8.6 (S), U8.8 (S), U8.10 (R), U10.1 (GND); also elsewhere on the board
CORE_CLOCK: R77.1, TP1.1; also elsewhere on the board
DIVIDER_1_OUT: Q2.3 (G), TP3.1, U8.1 (Q), U8.11 (C)
DIVIDER_2_OUT: R60.2, TP4.1, U8.13 (Q)
DIVIDER_IN: R92.2, U8.3 (C)
unnamed: C24.2, R87.1, R89.2
unnamed: Q2.2 (S), R59.2, U7.12 (+)
unnamed: Q3.2 (S), R70.2, U7.3 (+)
unnamed: Q4.1 (B), R77.2
unnamed: C24.1, Q4.2 (E), R82.2
unnamed: Q5.1 (B), R87.2
unnamed: C26.1, Q5.2 (E), R90.2, TP5.1
unnamed: R69.1, R70.1, R84.2, U7.8
unnamed: R72.1, U9.7
unnamed: R81.1, R86.2, U7.7
unnamed: R83.1, RV14.2
unnamed: R69.2, R71.1, U7.2 (-)
unnamed: R80.2, R86.1, U7.5 (+)
unnamed: R74.2, R83.2, R84.1, U7.9 (-)
unnamed: R76.2, R79.1, U7.13 (-)
unnamed: U8.9 (D), U8.12 (~Q)
unnamed: R60.1, U9.5 (+)
unnamed: R73.1, R88.2, U9.6 (-)
unnamed: C25.2, U10.5 (CV)
unnamed: R92.1, TP2.1, U10.3 (Q)
unnamed: C26.2, R93.1, R94.2, U10.2 (TR), U10.6 (THR)
PULSE_SUB: R78.1, R81.2; also elsewhere on the board
PULSE_SUB_2: R72.2, R85.1; also elsewhere on the board
PWM_LEVEL: U7.6 (-); also elsewhere on the board
RAMP: R59.1, R76.1; also elsewhere on the board
RAMP_SUB: R71.2, U7.1
TRIANGLE_SUB: R74.1, R79.2, R80.1, U7.14; also elsewhere on the board
_DIVIDER_1_OUT: Q3.3 (G), U8.2 (~Q), U8.5 (D)

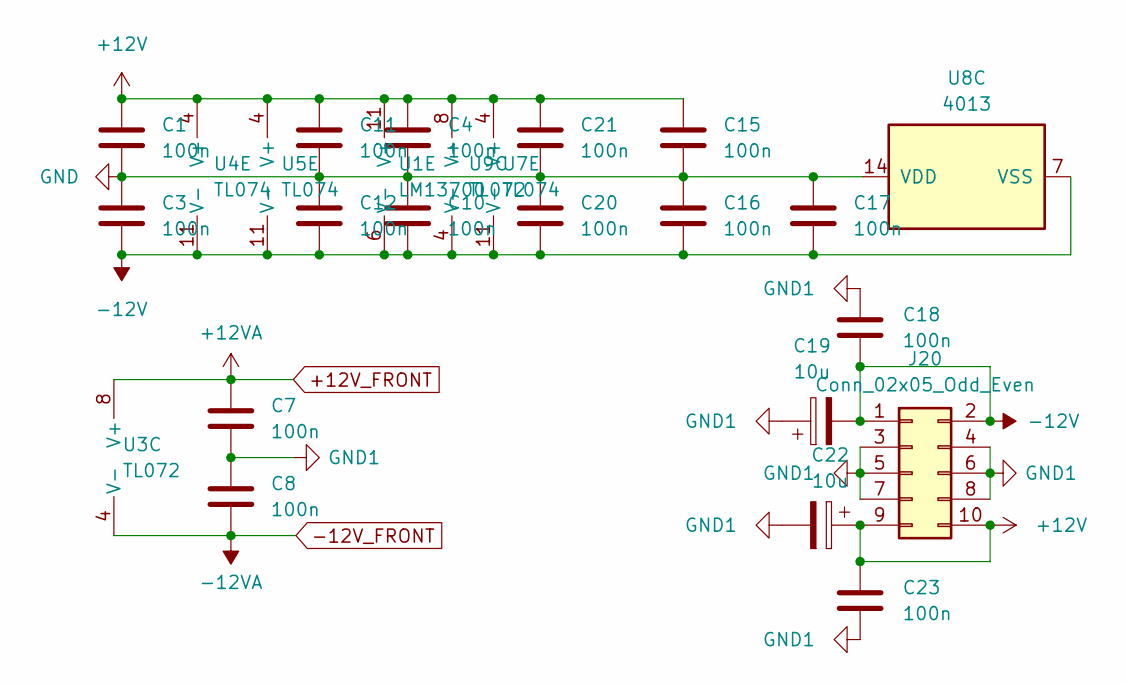
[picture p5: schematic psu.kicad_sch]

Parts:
C1, C3, C4, C7, C8, C10, C11, C12, C15, C16, C17, C18, C20, C21, C23: 100n; C_0603_1608Metric_Pad1.08x0.95mm_HandSolder
C19, C22: 10u; CP_Elec_4x5.8
J20: Conn_02x05_Odd_Even; IDC-Header_2x05_P2.54mm_Vertical
U1: LM13700; SOIC-16_3.9x9.9mm_P1.27mm
U3, U9: TL072; SOIC-8_3.9x4.9mm_P1.27mm
U4, U5, U7: TL074; SOIC-14_3.9x8.7mm_P1.27mm
U8: 4013; SOIC-14_3.9x8.7mm_P1.27mm

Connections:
+12V: C1.1, C4.1, C11.1, C15.1, C21.1, C22.1, C23.1, J20.9, J20.10, U1.11 (V+), U4.4 (V+), U5.4 (V+), U7.4 (V+), U9.8 (V+); also elsewhere on the board
+12V_FRONT: C7.1, U3.8 (V+); also elsewhere on the board
-12V: C3.2, C10.2, C12.2, C16.2, C17.2, C18.2, C19.2, C20.2, J20.1, J20.2, U1.6 (V-), U4.11 (V-), U5.11 (V-), U7.11 (V-), U8.7 (VSS), U9.4 (V-); also elsewhere on the board
-12V_FRONT: C8.2, U3.4 (V-); also elsewhere on the board

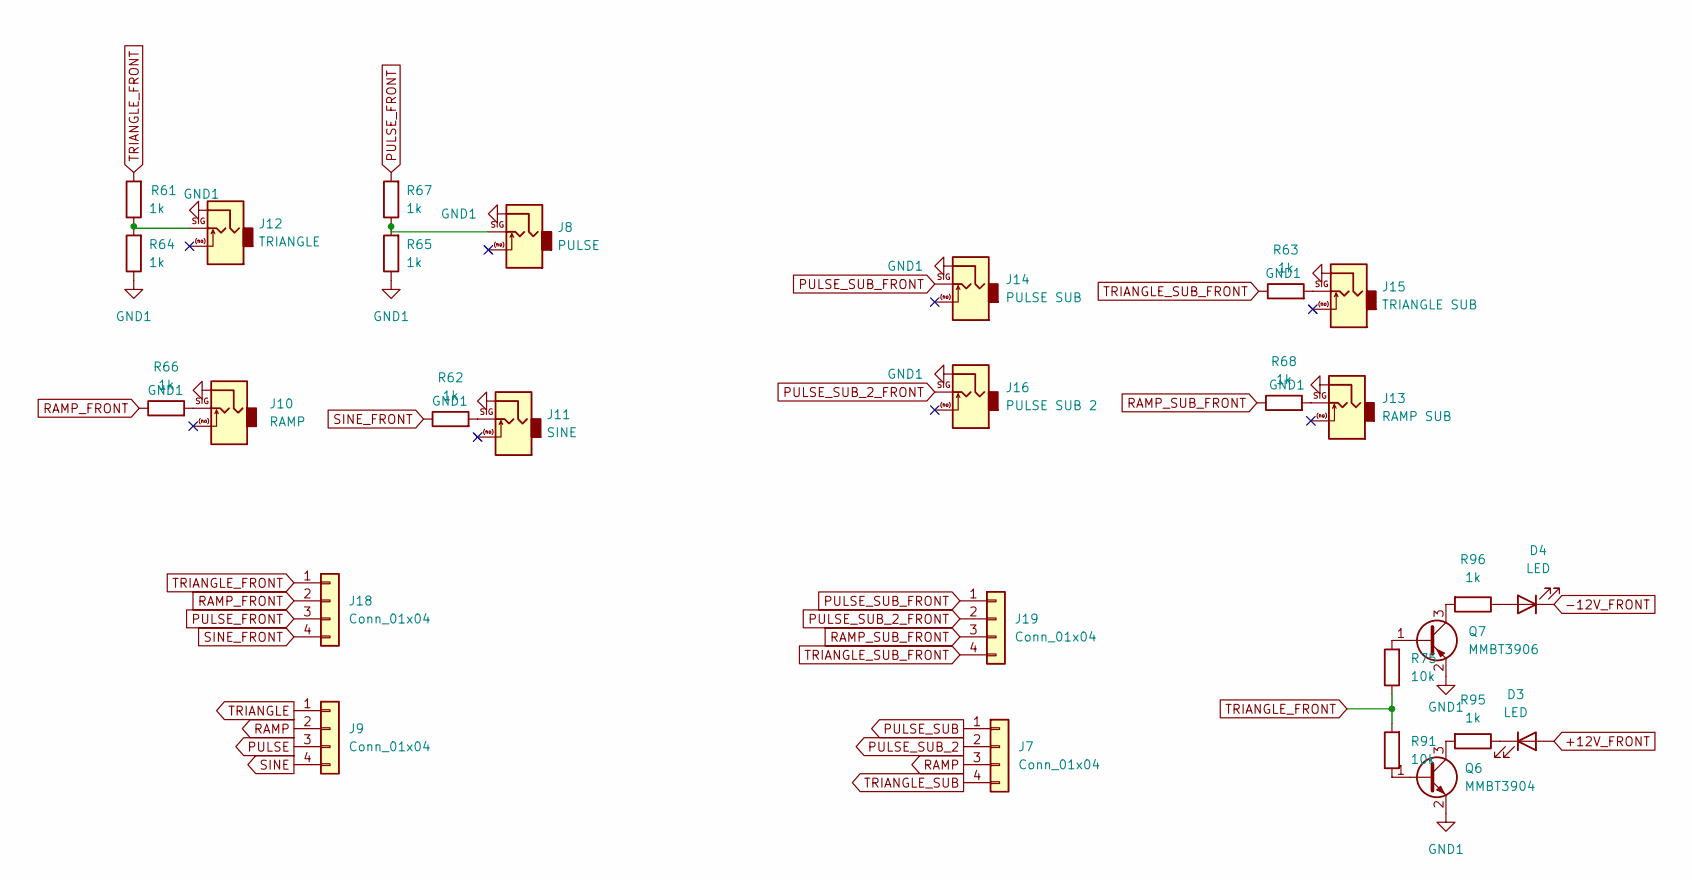
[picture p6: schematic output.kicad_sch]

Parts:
D3, D4: LED; LED_D3.0mm
J7, J9: Conn_01x04; PinSocket_1x04_P2.54mm_Vertical
J8: PULSE; Jack_3.5mm_QingPu_WQP-PJ398SM_Vertical_CircularHoles
J10: RAMP; Jack_3.5mm_QingPu_WQP-PJ398SM_Vertical_CircularHoles
J11: SINE; Jack_3.5mm_QingPu_WQP-PJ398SM_Vertical_CircularHoles
J12: TRIANGLE; Jack_3.5mm_QingPu_WQP-PJ398SM_Vertical_CircularHoles
J13: RAMP SUB; Jack_3.5mm_QingPu_WQP-PJ398SM_Vertical_CircularHoles
J14: PULSE SUB; Jack_3.5mm_QingPu_WQP-PJ398SM_Vertical_CircularHoles
J15: TRIANGLE SUB; Jack_3.5mm_QingPu_WQP-PJ398SM_Vertical_CircularHoles
J16: PULSE SUB 2; Jack_3.5mm_QingPu_WQP-PJ398SM_Vertical_CircularHoles
J18, J19: Conn_01x04; PinHeader_1x04_P2.54mm_Vertical
Q6: MMBT3904; SOT-23
Q7: MMBT3906; SOT-23
R61, R62, R63, R64, R65, R66, R67, R68, R95, R96: 1k; R_0603_1608Metric_Pad0.98x0.95mm_HandSolder
R75, R91: 10k; R_0603_1608Metric_Pad0.98x0.95mm_HandSolder

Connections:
+12V_FRONT: D3.2 (A); also elsewhere on the board
-12V_FRONT: D4.1 (K); also elsewhere on the board
unnamed: D3.1 (K), R95.1
unnamed: D4.2 (A), R96.1
unnamed: J8.T, R65.2, R67.1
unnamed: J10.T, R66.2
unnamed: J11.T, R62.2
unnamed: J12.T, R61.1, R64.2
unnamed: J13.T, R68.2
unnamed: J15.T, R63.2
unnamed: Q6.1 (B), R91.1
unnamed: Q6.3 (C), R95.2
unnamed: Q7.1 (B), R75.2
unnamed: Q7.3 (C), R96.2
PULSE: J9.3; also elsewhere on the board
PULSE_FRONT: J18.3, R67.2
PULSE_SUB: J7.1; also elsewhere on the board
PULSE_SUB_2: J7.2; also elsewhere on the board
PULSE_SUB_2_FRONT: J16.T, J19.2
PULSE_SUB_FRONT: J14.T, J19.1
RAMP: J7.3, J9.2; also elsewhere on the board
RAMP_FRONT: J18.2, R66.1
RAMP_SUB_FRONT: J19.3, R68.1
SINE: J9.4; also elsewhere on the board
SINE_FRONT: J18.4, R62.1
TRIANGLE: J9.1; also elsewhere on the board
TRIANGLE_FRONT: J18.1, R61.2, R75.1, R91.2
TRIANGLE_SUB: J7.4; also elsewhere on the board
TRIANGLE_SUB_FRONT: J19.4, R63.1

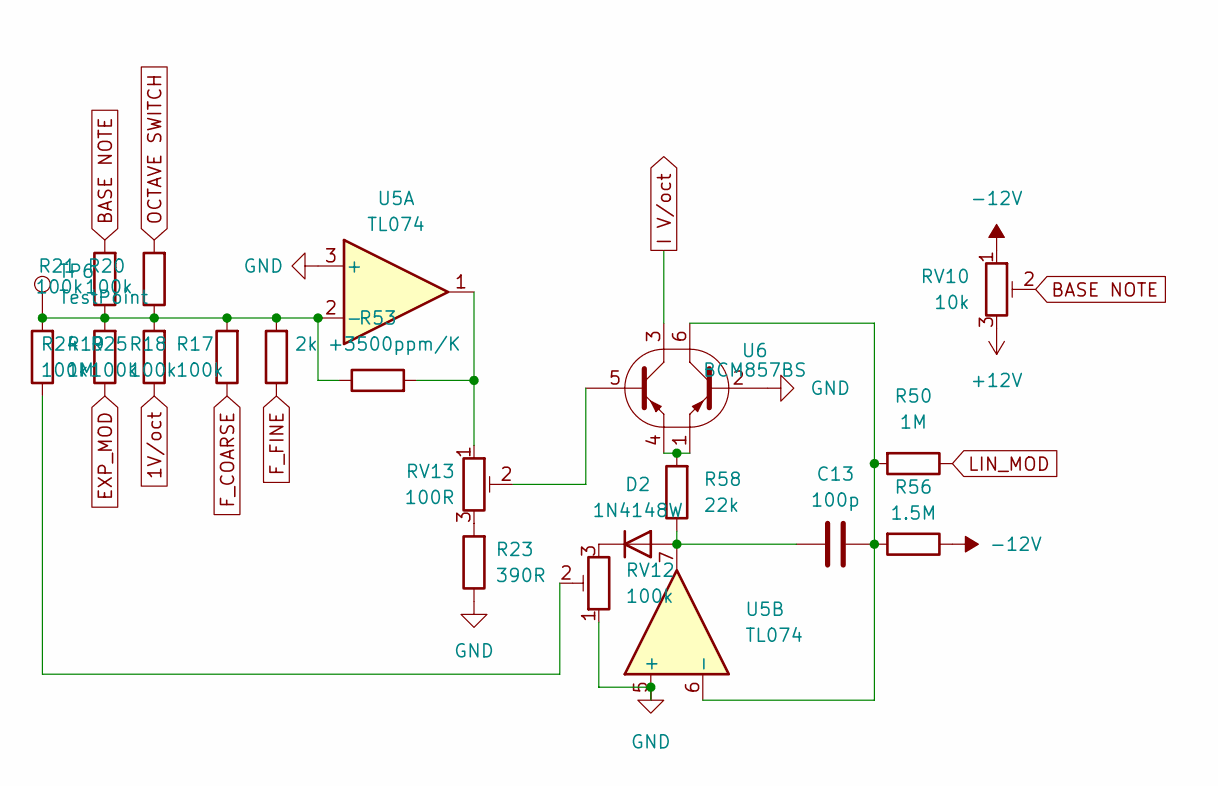
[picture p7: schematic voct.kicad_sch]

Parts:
C13: 100p; C_0603_1608Metric_Pad1.08x0.95mm_HandSolder
D2: 1N4148W; D_SOD-123
R17, R18, R20, R21, R24, R25: 100k; R_0603_1608Metric_Pad0.98x0.95mm_HandSolder
R19, R50: 1M; R_0603_1608Metric_Pad0.98x0.95mm_HandSolder
R23: 390R; R_0603_1608Metric_Pad0.98x0.95mm_HandSolder
R53: 2k +3500ppm/K; R_0603_1608Metric_Pad0.98x0.95mm_HandSolder
R56: 1.5M; R_0603_1608Metric_Pad0.98x0.95mm_HandSolder
R58: 22k; R_0603_1608Metric_Pad0.98x0.95mm_HandSolder
RV10: 10k; Potentiometer_Bourns_3214X_Vertical
RV12: 100k; Potentiometer_Bourns_3214X_Vertical
RV13: 100R; Potentiometer_Bourns_3214X_Vertical
TP6: TestPoint; TestPoint_Pad_D1.0mm
U5: TL074; SOIC-14_3.9x8.7mm_P1.27mm
U6: BCM857BS; SOT-363_SC-70-6

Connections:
1V/oct: R17.1; also elsewhere on the board
+12V: RV10.3; also elsewhere on the board
-12V: R56.1, RV10.1; also elsewhere on the board
BASE NOTE: R21.2, RV10.2
EXP_MOD: R18.1; also elsewhere on the board
F_COARSE: R24.1; also elsewhere on the board
F_FINE: R25.1; also elsewhere on the board
I V/oct: U6.3; also elsewhere on the board
LIN_MOD: R50.1; also elsewhere on the board
unnamed: C13.1, D2.2 (A), R58.1, U5.7
unnamed: D2.1 (K), RV12.3
unnamed: R19.1, RV12.2
unnamed: R23.2, RV13.3
unnamed: R53.2, RV13.1, U5.1
unnamed: R58.2, U6.1, U6.4
unnamed: RV13.2, U6.5
unnamed: R17.2, R18.2, R19.2, R20.1, R21.1, R24.2, R25.2, R53.1, TP6.1, U5.2 (-)
unnamed: C13.2, R50.2, R56.2, U5.6 (-), U6.6
OCTAVE SWITCH: R20.2; also elsewhere on the board

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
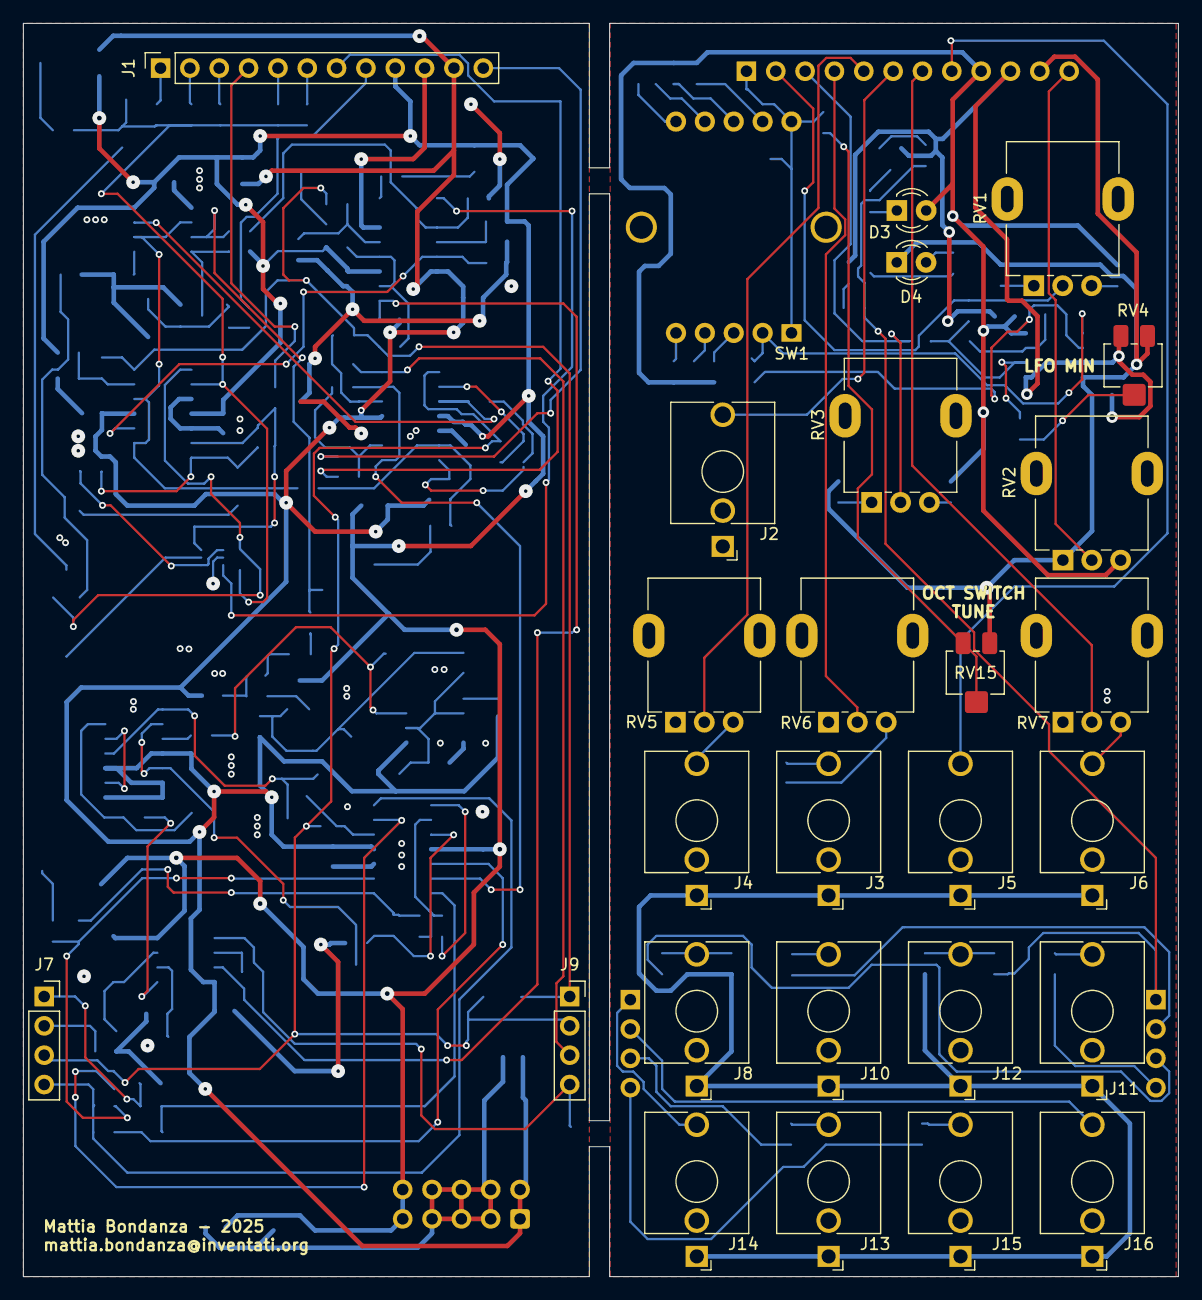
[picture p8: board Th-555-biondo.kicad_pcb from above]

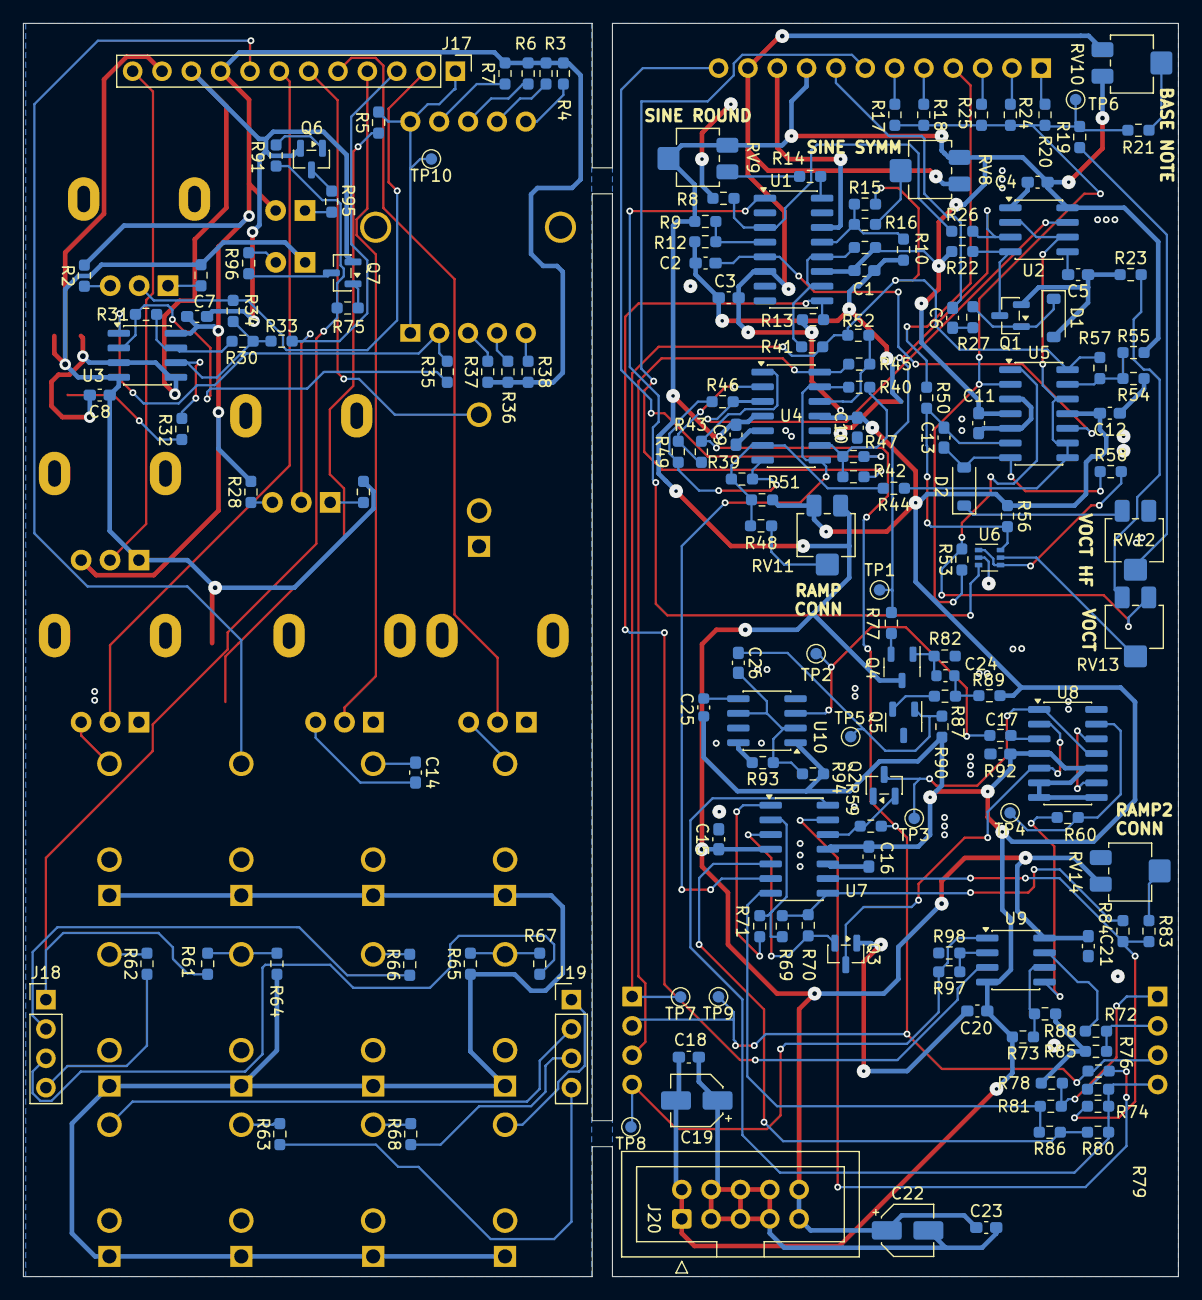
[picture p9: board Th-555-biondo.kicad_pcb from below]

Board: 2 copper layers, 100.0 x 108.5 mm, 191 parts (164 on the bottom side), 133 nets.

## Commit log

2025-11-21 First commit, this is already version v 0.3
    [Th-555-biondo.kicad_pcb, Th-555-biondo.kicad_sch, Th-555-biondo_front.kicad_pcb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]
2025-11-21 Added production files
    [BOM-Th-555-biondo.csv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]
